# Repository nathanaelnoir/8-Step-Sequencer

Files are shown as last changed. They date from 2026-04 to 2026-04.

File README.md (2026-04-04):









<h1>ℤ₈ Modulo-8 Sequencer</h1>

Modulo-8 Sequencer is an 8-step Eurorack sequencer with an onboard clock, external clock/reset inputs, and separate clock, gate, and CV outputs.

## Contents

- Overview
- Features
- Build & assembly notes
- Testing
- License & contributing

## Overview

This repository contains the KiCad 9 design files for Modulo-8 Sequencer, a straightforward 8-step CV/gate sequencer for Eurorack. Eight pots set the step voltages, the LEDs show the current position, and the module can run from its own clock or from an external pulse. `CLOCK OUT`, `GATE OUT`, `CV OUT`, and `RESET` are all available on the front panel.

## Features

- 8-step sequencer built around `CD4017BE` and `TL074`.
- Internal clock plus external `CLOCK IN`.
- Separate `CLOCK OUT`, `GATE OUT`, `CV OUT`, and `RESET` jacks.
- Eight 100 k step pots for setting the sequence voltage.
- Eight step LEDs for visual feedback.
- Rotary switch wired across `Count0` to `Count7` for loop-length / step-count selection.
- Standard Eurorack power: `+12 V / -12 V / GND` on a 10-pin header.
- Mixed build: SMD passives, diodes, and transistors, with through-hole panel hardware.

## Build & assembly notes

- Check pin-1 orientation on `U1` (`TL074`) and `U3` (`CD4017BE`) before soldering.
- Double-check the Eurorack power header orientation before applying power. Getting that wrong is an easy way to ruin the build.
- Panel hardware is not minimal: five 3.5 mm jacks, eight step pots, eight LEDs, several toggle switches, one rotary switch, and two trimmers (`RV1`, `RV2`).
- The power section includes ferrite beads and local decoupling on the rails. Populate it exactly as shown.
- This is a mixed SMD + THT build, so it makes sense to solder the low-profile SMD parts first and leave the panel hardware for last.

## Testing

1. Power the module from a current-limited Eurorack supply and verify `+12 V`, `-12 V`, and `GND` at the header and test points before patching anything.
2. Let the internal clock run and check that the step LEDs advance in order and that `CLOCK OUT` is pulsing.
3. Feed a known clock into `CLOCK IN` and confirm the sequence advances cleanly from the external source.
4. Trigger `RESET` and make sure the sequencer returns to step 1 or to the selected loop point.
5. Watch `GATE OUT` and `CV OUT` on a scope or with downstream modules and confirm that the outputs follow the programmed steps.

## License & contributing

No `LICENSE` file has been added to this repository yet. Until that changes, assume the design is shared for reference, not under an explicit open-source license.

If a license is added later, this section can be updated properly.

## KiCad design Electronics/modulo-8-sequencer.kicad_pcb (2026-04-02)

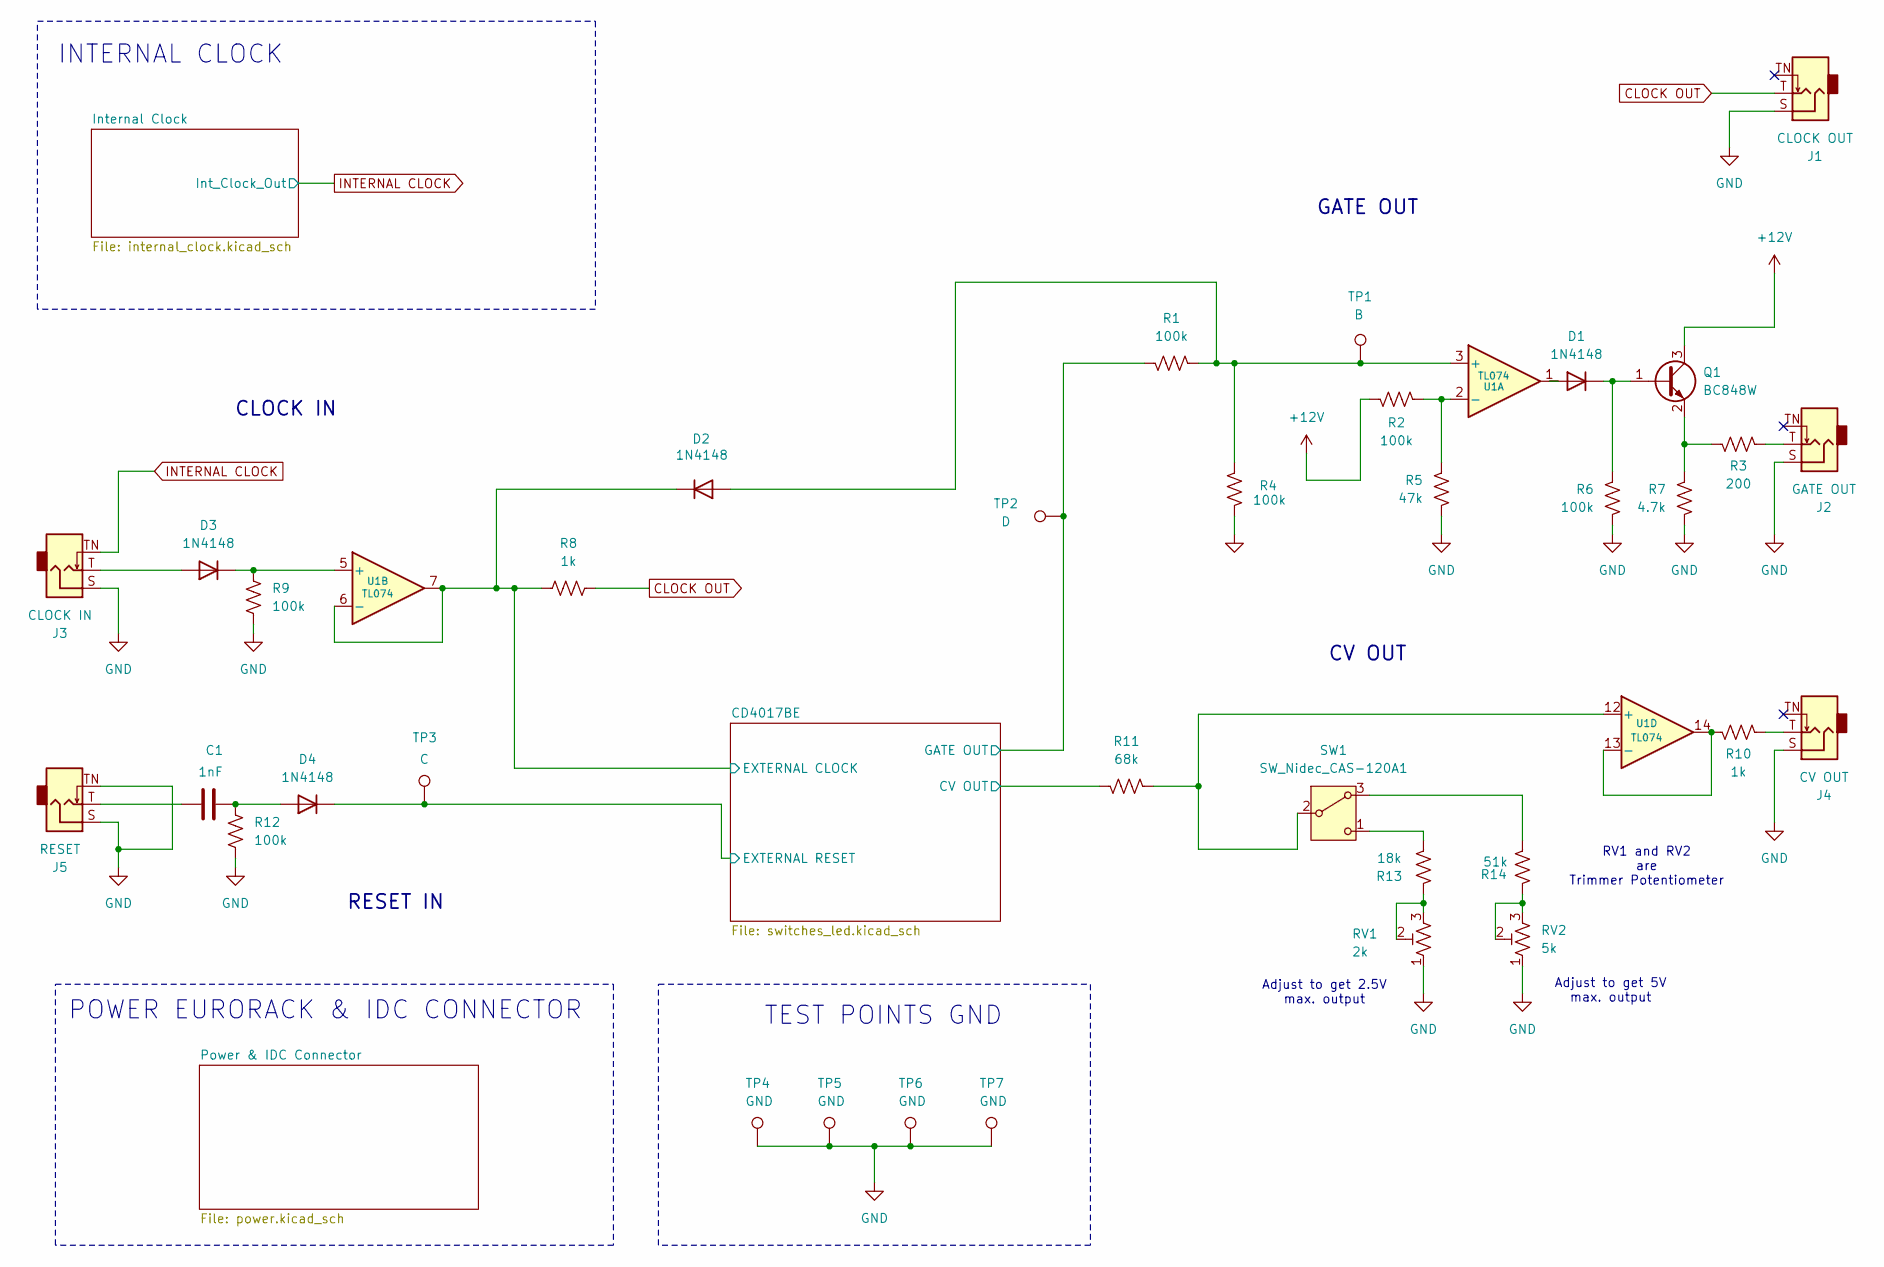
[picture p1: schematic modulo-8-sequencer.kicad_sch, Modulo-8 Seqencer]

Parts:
C1: 1nF; C_0805_2012Metric_Pad1.18x1.45mm_HandSolder
D1, D2, D3, D4: 1N4148; D_SOD-323_HandSoldering
J1: CLOCK OUT; Jack_3.5mm_QingPu_WQP-PJ398SM_Vertical
J2: GATE OUT; Jack_3.5mm_QingPu_WQP-PJ398SM_Vertical
J3: CLOCK IN; Jack_3.5mm_QingPu_WQP-PJ398SM_Vertical
J4: CV OUT; Jack_3.5mm_QingPu_WQP-PJ398SM_Vertical
J5: RESET; Jack_3.5mm_QingPu_WQP-PJ398SM_Vertical
Q1: BC848W; SOT-323_SC-70
R1, R2, R4, R6, R9, R12: 100k; R_0805_2012Metric_Pad1.20x1.40mm_HandSolder
R3: 200; R_0805_2012Metric_Pad1.20x1.40mm_HandSolder
R5: 47k; R_0805_2012Metric_Pad1.20x1.40mm_HandSolder
R7: 4.7k; R_0805_2012Metric_Pad1.20x1.40mm_HandSolder
R8, R10: 1k; R_0805_2012Metric_Pad1.20x1.40mm_HandSolder
R11: 68k; R_0805_2012Metric_Pad1.20x1.40mm_HandSolder
R13: 18k; R_0805_2012Metric_Pad1.20x1.40mm_HandSolder
R14: 51k; R_0805_2012Metric_Pad1.20x1.40mm_HandSolder
RV1: 2k; Trimmer_Bourns_3296W_50k_THT
RV2: 5k; Trimmer_Bourns_3296W_50k_THT
SW1: SW_Nidec_CAS-120A1; Switch_Toggle_Dailywell_MS1T1B1M2QES_SPDT
TP1: B; TestPoint_Pad_D1.5mm
TP2: D; TestPoint_Pad_D1.5mm
TP3: C; TestPoint_Pad_D1.5mm
TP4, TP5, TP6, TP7: GND; TestPoint_Pad_D1.5mm
U1: TL074; SOIC-14_3.9x8.7mm_P1.27mm

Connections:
+12V: Q1.3 (C), R2.1; also elsewhere on the board
/CD4017BE/CV OUT: R11.1; also elsewhere on the board
/CD4017BE/EXTERNAL CLOCK: D2.1 (K), R8.2, U1.6 (-), U1.7; also elsewhere on the board
/CD4017BE/EXTERNAL RESET: D4.1 (K), TP3.1; also elsewhere on the board
/CD4017BE/GATE OUT: R1.1, TP2.1; also elsewhere on the board
CLOCK OUT: J1.T, R8.1
GND: J1.S, J2.S, J3.S, J4.S, J5.S, J5.TN, R4.1, R5.1, R6.1, R7.1, R9.1, R12.1, RV1.1, RV2.1, TP4.1, TP5.1, TP6.1, TP7.1; also elsewhere on the board
INTERNAL CLOCK: J3.TN; also elsewhere on the board
unnamed: C1.2, J5.T
unnamed: D1.2 (A), U1.1
unnamed: D1.1 (K), Q1.1 (B), R6.2
unnamed: D2.2 (A), R1.2, R4.2, TP1.1, U1.3 (+)
unnamed: D3.2 (A), J3.T
unnamed: D3.1 (K), R9.2, U1.5 (+)
unnamed: C1.1, D4.2 (A), R12.2
unnamed: J2.T, R3.1
unnamed: J4.T, R10.1
unnamed: Q1.2 (E), R3.2, R7.2
unnamed: R13.1, RV1.2, RV1.3
unnamed: R14.1, RV2.2, RV2.3
unnamed: R14.2, SW1.3 (A)
unnamed: R11.2, SW1.2 (B), U1.12 (+)
unnamed: R13.2, SW1.1 (C)
unnamed: R2.2, R5.2, U1.2 (-)
unnamed: R10.2, U1.13 (-), U1.14

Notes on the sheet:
POWER EURORACK & IDC CONNECTOR
Adjust to get 2.5V max. output
RV1 and RV2 are Trimmer Potentiometer
TEST POINTS GND
INTERNAL CLOCK
Adjust to get 5V max. output
CV OUT
GATE OUT
RESET IN
CLOCK IN

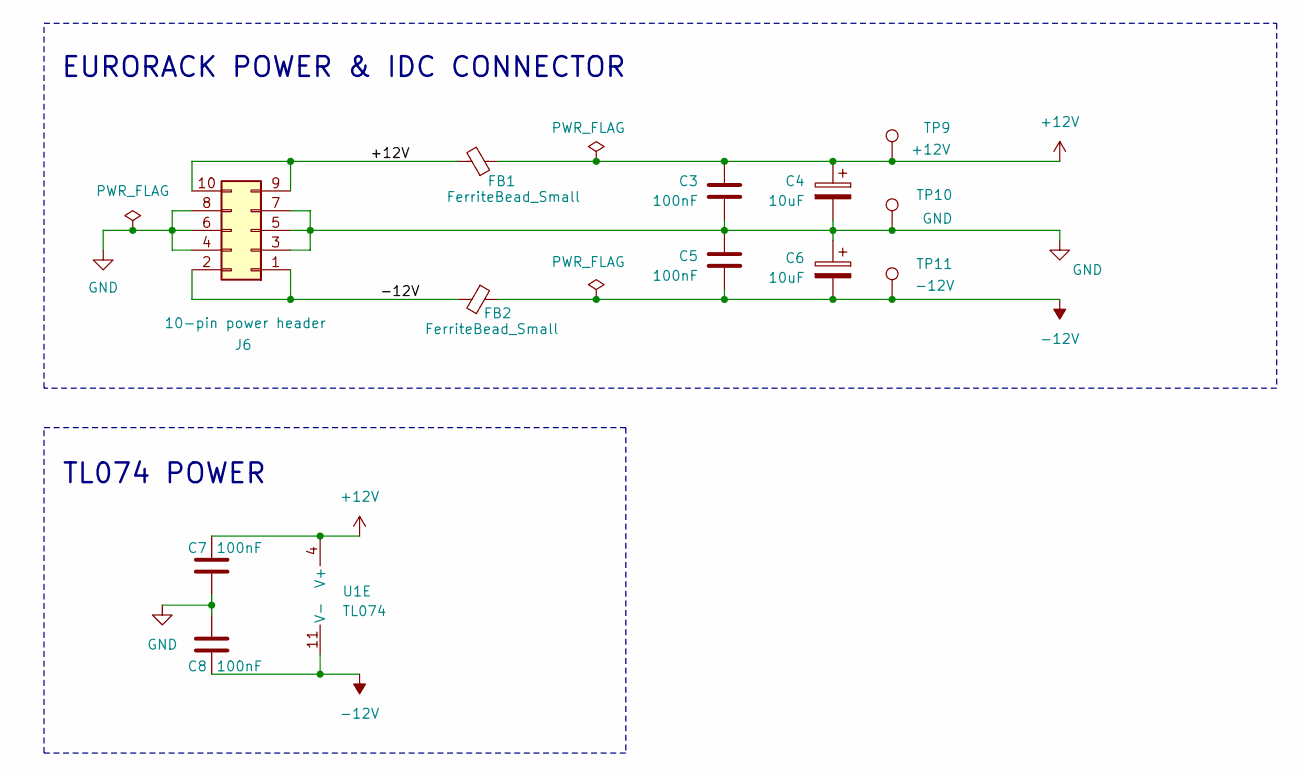
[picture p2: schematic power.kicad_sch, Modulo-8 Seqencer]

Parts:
C3, C5, C7, C8: 100nF; C_0805_2012Metric_Pad1.18x1.45mm_HandSolder
C4, C6: 10uF; CP_Elec_5x5.4
FB1, FB2: FerriteBead_Small; L_0805_2012Metric_Pad1.05x1.20mm_HandSolder
J6: 10-pin power header; IDC-Header_2x05_P2.54mm_Vertical
TP9: +12V; TestPoint_Pad_D1.5mm
TP10: GND; TestPoint_Pad_D1.5mm
TP11: -12V; TestPoint_Pad_D1.5mm
U1: TL074; SOIC-14_3.9x8.7mm_P1.27mm

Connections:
+12V: C3.1, C4.1, C7.1, FB1.1, FB1.2, J6.9, J6.10, TP9.1, U1.4 (V+); also elsewhere on the board
-12V: C5.2, C6.2, C8.2, FB2.1, FB2.2, J6.1, J6.2, TP11.1, U1.11 (V-)
GND: C3.2, C4.2, C5.1, C6.1, C7.2, C8.1, J6.3, J6.4, J6.5, J6.6, J6.7, J6.8, TP10.1; also elsewhere on the board

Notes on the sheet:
TL074 POWER
EURORACK POWER & IDC CONNECTOR

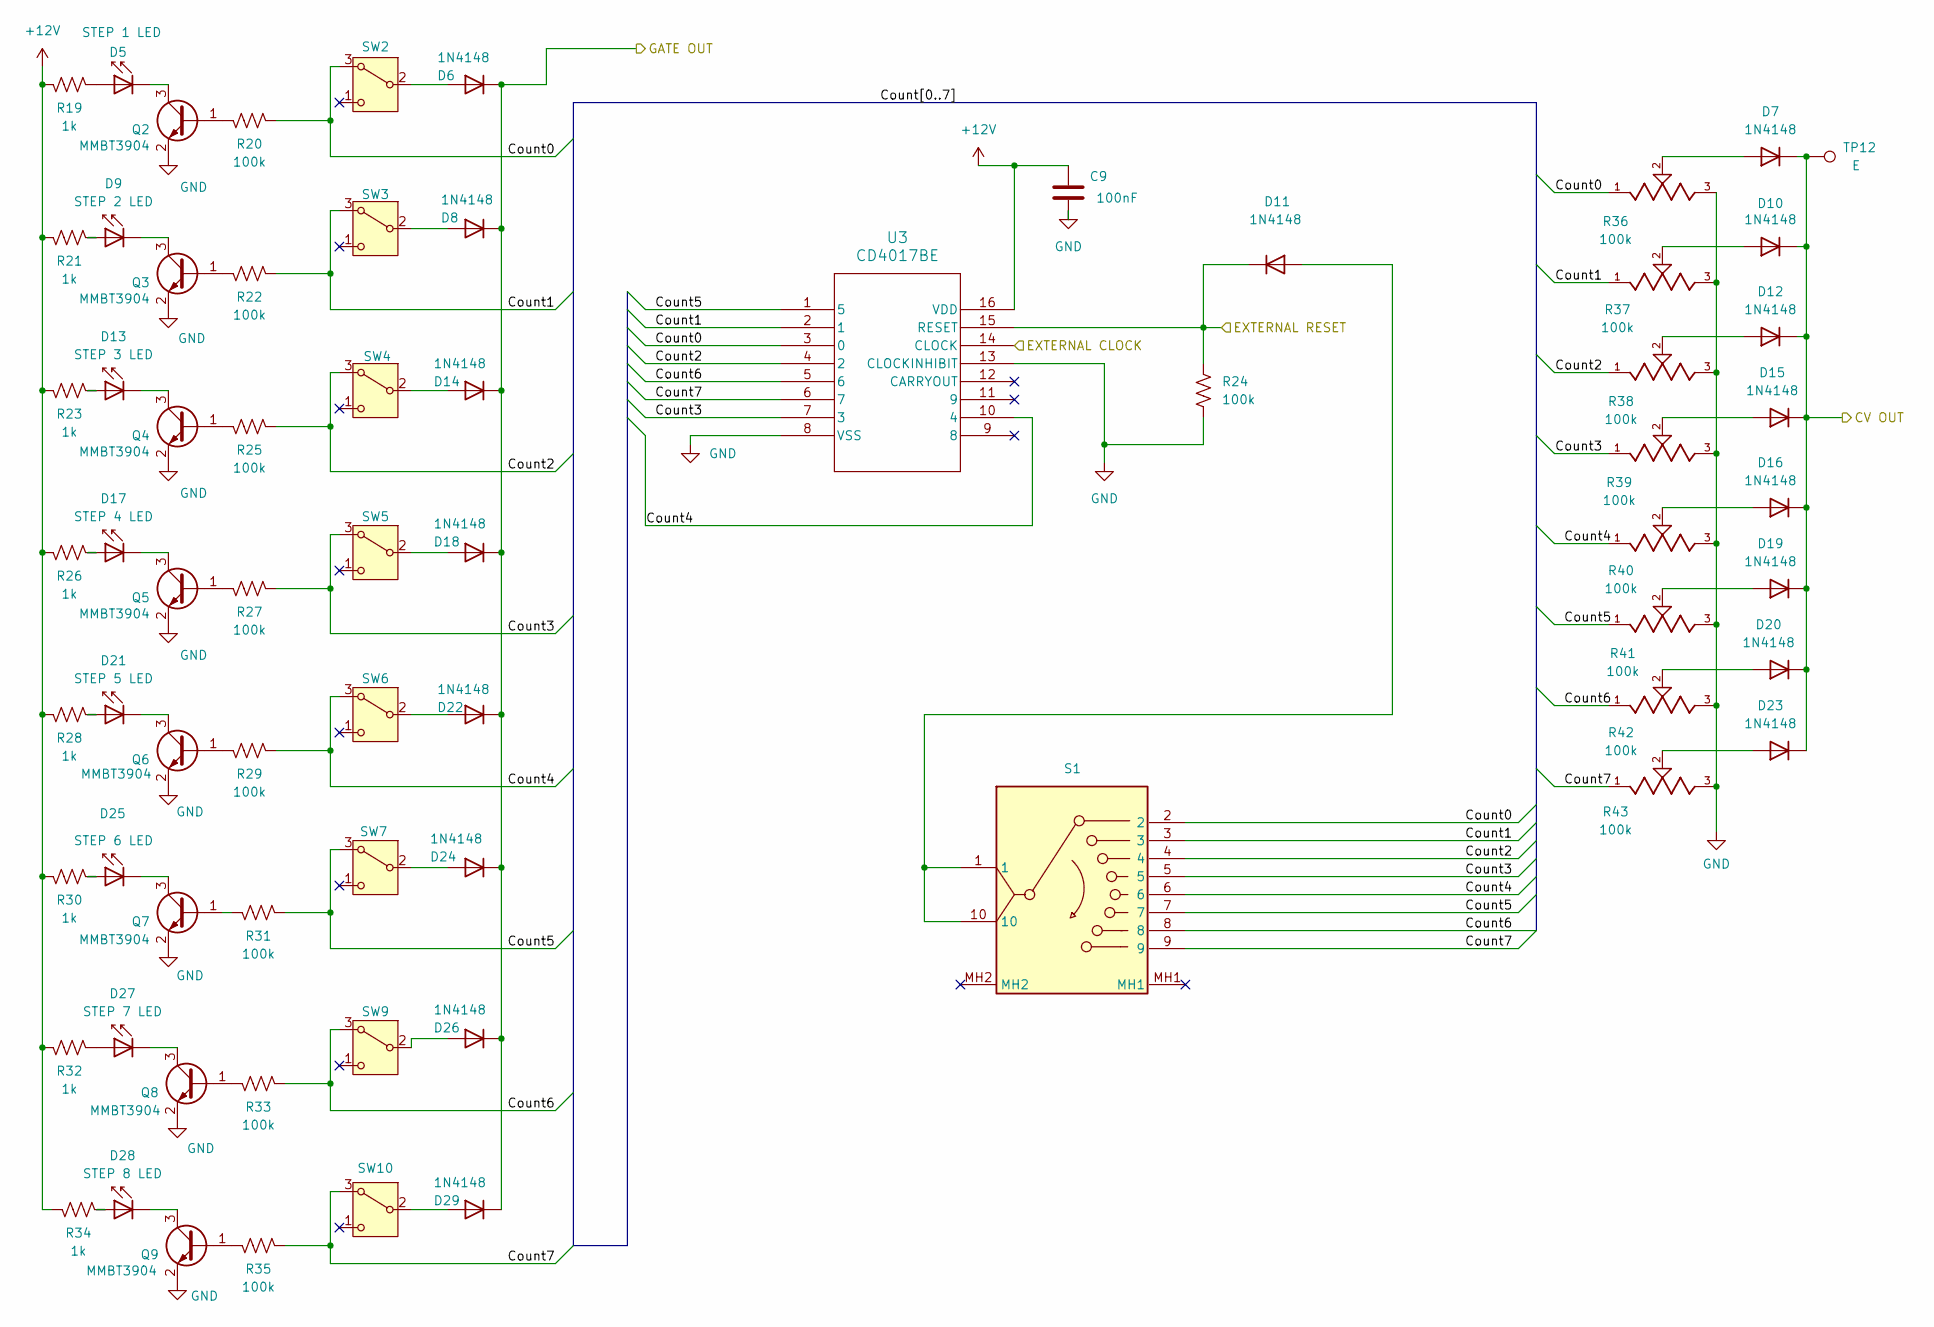
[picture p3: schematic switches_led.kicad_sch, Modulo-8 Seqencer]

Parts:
C9: 100nF; C_0805_2012Metric_Pad1.18x1.45mm_HandSolder
D5: STEP 1 LED; LED_D3.0mm_Clear
D6, D7, D8, D10, D11, D12, D14, D15, D16, D18, D19, D20, D22, D23, D24, D26, D29: 1N4148; D_SOD-323_HandSoldering
D9: STEP 2 LED; LED_D3.0mm_Clear
D13: STEP 3 LED; LED_D3.0mm_Clear
D17: STEP 4 LED; LED_D3.0mm_Clear
D21: STEP 5 LED; LED_D3.0mm_Clear
D25: STEP 6 LED; LED_D3.0mm_Clear
D27: STEP 7 LED; LED_D3.0mm_Clear
D28: STEP 8 LED; LED_D3.0mm_Clear
Q2, Q3, Q4, Q5, Q6, Q7, Q8, Q9: MMBT3904; SOT-23
R19, R21, R23, R26, R28, R30, R32, R34: 1k; R_0805_2012Metric_Pad1.20x1.40mm_HandSolder
R20, R22, R24, R25, R27, R29, R31, R33, R35: 100k; R_0805_2012Metric_Pad1.20x1.40mm_HandSolder
R36, R37, R38, R39, R40, R41, R42, R43: 100k; Potentiometer_Alpha_RD901F_Vertical_Alt
S1: Switch_Rotary_Alpha_SR1712F_1P8T; Mouser Part Number 105-SR1712F-18NS
SW2, SW3, SW4, SW5, SW6, SW7, SW9, SW10: Switch_Toggle_Dailywell_MS1T1B1M2QES_SPDT
TP12: E; TestPoint_Pad_D1.5mm
U3: CD4017BE; IC_DIP-16_CD4017BE_THT

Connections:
+12V: C9.1, R19.1, R21.1, R23.1, R26.1, R28.1, R30.1, R32.1, R34.1, U3.16 (VDD); also elsewhere on the board
/CD4017BE/CV OUT: D7.1 (K), D10.1 (K), D12.1 (K), D15.1 (K), D16.1 (K), D19.1 (K), D20.1 (K), D23.1 (K), TP12.1; also elsewhere on the board
/CD4017BE/Count0: R20.2, R36.1, S1.2, SW2.3 (A), U3.3 (0)
/CD4017BE/Count1: R22.2, R37.1, S1.3, SW3.3 (A), U3.2 (1)
/CD4017BE/Count2: R25.2, R38.1, S1.4, SW4.3 (A), U3.4 (2)
/CD4017BE/Count3: R27.2, R39.1, S1.5, SW5.3 (A), U3.7 (3)
/CD4017BE/Count4: R29.2, R40.1, S1.6, SW6.3 (A), U3.10 (4)
/CD4017BE/Count5: R31.2, R41.1, S1.7, SW7.3 (A), U3.1 (5)
/CD4017BE/Count6: R33.2, R42.1, S1.8, SW9.3 (A), U3.5 (6)
/CD4017BE/Count7: R35.2, R43.1, S1.9, SW10.3 (A), U3.6 (7)
/CD4017BE/EXTERNAL CLOCK: U3.14 (CLOCK); also elsewhere on the board
/CD4017BE/EXTERNAL RESET: D11.1 (K), R24.2, U3.15 (RESET); also elsewhere on the board
/CD4017BE/GATE OUT: D6.1 (K), D8.1 (K), D14.1 (K), D18.1 (K), D22.1 (K), D24.1 (K), D26.1 (K), D29.1 (K); also elsewhere on the board
GND: C9.2, Q2.2 (E), Q3.2 (E), Q4.2 (E), Q5.2 (E), Q6.2 (E), Q7.2 (E), Q8.2 (E), Q9.2 (E), R24.1, R36.3, R37.3, R38.3, R39.3, R40.3, R41.3, R42.3, R43.3, U3.8 (VSS), U3.13 (CLOCKINHIBIT); also elsewhere on the board
unnamed: D5.2 (A), R19.2
unnamed: D5.1 (K), Q2.3 (C)
unnamed: D6.2 (A), SW2.2 (B)
unnamed: D7.2 (A), R36.2
unnamed: D8.2 (A), SW3.2 (B)
unnamed: D9.2 (A), R21.2
unnamed: D9.1 (K), Q3.3 (C)
unnamed: D10.2 (A), R37.2
unnamed: D11.2 (A), S1.1, S1.10
unnamed: D12.2 (A), R38.2
unnamed: D13.2 (A), R23.2
unnamed: D13.1 (K), Q4.3 (C)
unnamed: D14.2 (A), SW4.2 (B)
unnamed: D15.2 (A), R39.2
unnamed: D16.2 (A), R40.2
unnamed: D17.2 (A), R26.2
unnamed: D17.1 (K), Q5.3 (C)
unnamed: D18.2 (A), SW5.2 (B)
unnamed: D19.2 (A), R41.2
unnamed: D20.2 (A), R42.2
unnamed: D21.2 (A), R28.2
unnamed: D21.1 (K), Q6.3 (C)
unnamed: D22.2 (A), SW6.2 (B)
unnamed: D23.2 (A), R43.2
unnamed: D24.2 (A), SW7.2 (B)
unnamed: D25.2 (A), R30.2
unnamed: D25.1 (K), Q7.3 (C)
unnamed: D26.2 (A), SW9.2 (B)
unnamed: D27.2 (A), R32.2
unnamed: D27.1 (K), Q8.3 (C)
unnamed: D28.2 (A), R34.2
unnamed: D28.1 (K), Q9.3 (C)
unnamed: D29.2 (A), SW10.2 (B)
unnamed: Q2.1 (B), R20.1
unnamed: Q3.1 (B), R22.1
unnamed: Q4.1 (B), R25.1
unnamed: Q5.1 (B), R27.1
unnamed: Q6.1 (B), R29.1
unnamed: Q7.1 (B), R31.1
unnamed: Q8.1 (B), R33.1
unnamed: Q9.1 (B), R35.1

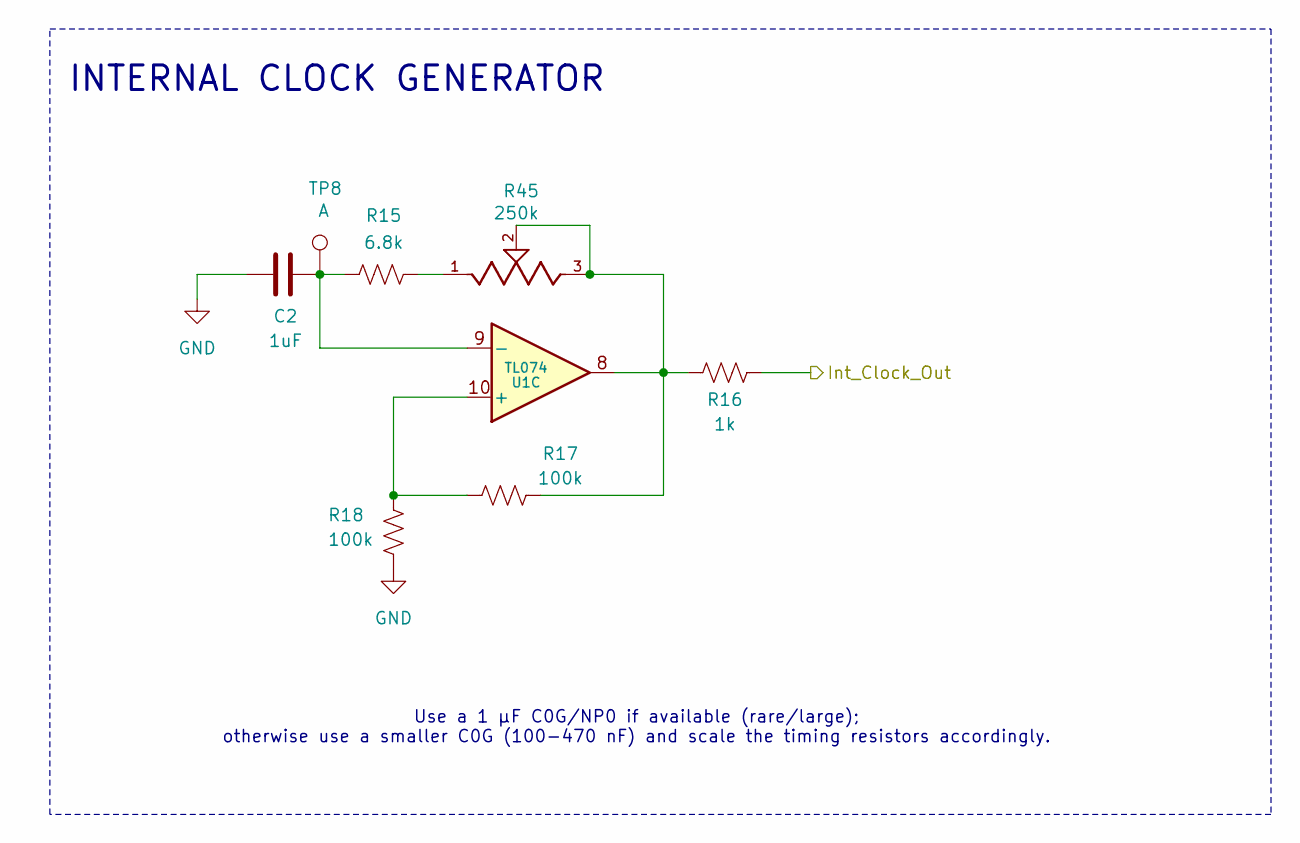
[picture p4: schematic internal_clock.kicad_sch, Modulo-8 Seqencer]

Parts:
C2: 1uF; Capacitor_Film_KEMET_R82DC4100AA60J_THT
R15: 6.8k; R_0805_2012Metric_Pad1.20x1.40mm_HandSolder
R16: 1k; R_0805_2012Metric_Pad1.20x1.40mm_HandSolder
R17, R18: 100k; R_0805_2012Metric_Pad1.20x1.40mm_HandSolder
R45: 250k; Potentiometer_Alpha_RD901F_Vertical_Alt
TP8: A; TestPoint_Pad_D1.5mm
U1: TL074; SOIC-14_3.9x8.7mm_P1.27mm

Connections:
GND: C2.1, R18.1; also elsewhere on the board
INTERNAL CLOCK: R16.1; also elsewhere on the board
unnamed: R15.1, R45.1
unnamed: R16.2, R17.1, R45.2, R45.3, U1.8
unnamed: R17.2, R18.2, U1.10 (+)
unnamed: C2.2, R15.2, TP8.1, U1.9 (-)

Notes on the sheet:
INTERNAL CLOCK GENERATOR
Use a 1 µF C0G/NP0 if available (rare/large); otherwise use a smaller C0G (100-470 nF) and scale the timing resistors accordingly.

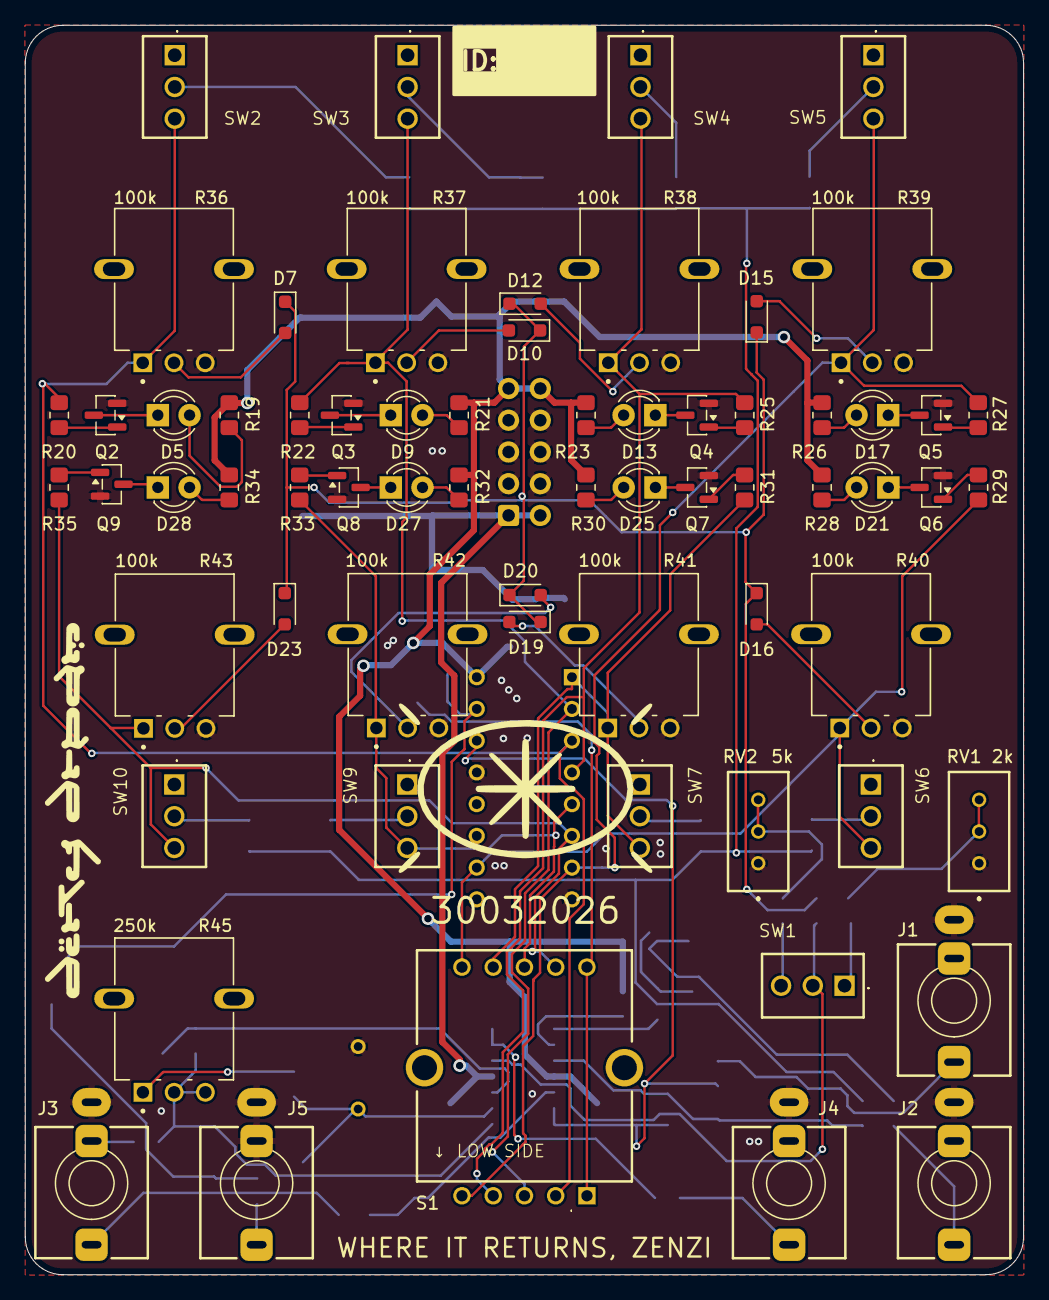
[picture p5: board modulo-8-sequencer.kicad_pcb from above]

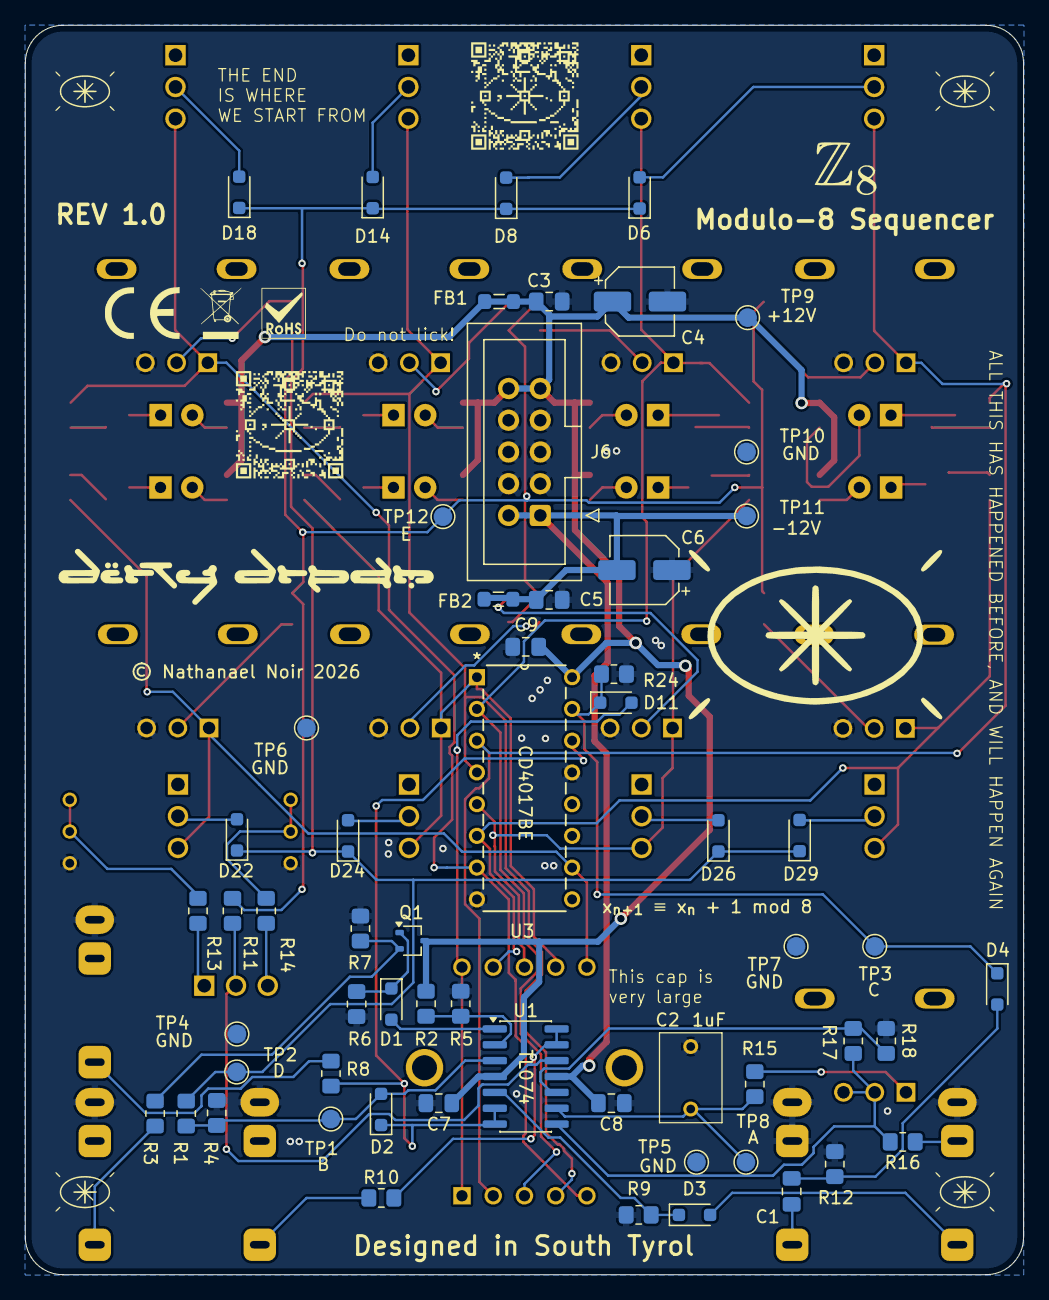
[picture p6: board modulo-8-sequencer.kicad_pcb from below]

Board: 2 copper layers, 79.9 x 100.0 mm, 125 parts (59 on the bottom side), 79 nets.

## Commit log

2026-03-09 schematic: update cicada schematic
    [internal_clock.kicad_sch, power.kicad_sch, sequencer.kicad_sch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]
2026-03-10 refactor(kicad): move switch/LED driver logic into switches_led sheet
    [power.kicad_sch, sequencer.kicad_sch, switches_led.kicad_sch]
2026-03-10 refactor(kicad): finishing root
    [sequencer.kicad_sch, switches_led.kicad_sch]
2026-03-10 refactor(kicad): first ERC run
    [sequencer.kicad_sch, switches_led.kicad_sch]
2026-03-13 Refine KiCad schematics for power, test points, and control values
    - replace schematic +12V/-12V global labels with proper power symbols
    - add GND test points and reorganize the power/IDC and main sequencer
    sheets
    - retune sequencer values including R33/R34 to 51k, R35 to 68k, C8 to
    1nF, and trim pots to 2k/5k
    - update switch/LED sheet labels and pot values, renaming LEDs by step
    and changing B250k controls to B100k
    - relax the KiCad four-way junction ERC setting in the project file
    [power.kicad_sch, sequencer.kicad_sch, switches_led.kicad_sch]
2026-03-13 Updating sheet names
    [internal_clock.kicad_sch, power.kicad_sch, sequencer.kicad_sch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]
2026-03-14 adding missing footprints to the power supply
    [power.kicad_sch]
2026-03-15 adding missing SMD footprints
    [internal_clock.kicad_sch, power.kicad_sch, sequencer.kicad_sch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]
2026-03-15 adding Test Point D
    [internal_clock.kicad_sch, power.kicad_sch, sequencer.kicad_sch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]
2026-03-16 adding footprints
    [sequencer.kicad_sch, switches_led.kicad_sch]
2026-03-18 adding footprint for rotary switch P1S8
    [sequencer.kicad_sch, switches_led.kicad_sch]
2026-03-19 adding new rotary switch
    [switches_led.kicad_sch]
2026-03-19 initiating pcb layout
    [internal_clock.kicad_sch, power.kicad_sch, sequencer.kicad_pcb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]
2026-03-21 placing layout frontview
    [internal_clock.kicad_sch, power.kicad_sch, sequencer.kicad_pcb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]
2026-03-21 fixing some errors in schematics; first component placement
    [power.kicad_sch, sequencer.kicad_pcb, switches_led.kicad_sch]
2026-03-22 connecting all components and adding copper layers, vias tracks…
    [sequencer.kicad_pcb]
2026-03-23 rerouting and editing silkscreen
    [sequencer.kicad_pcb]
2026-03-24 re-placing components; optimizing text on silkscreen
    [internal_clock.kicad_sch, sequencer.kicad_pcb, sequencer.kicad_sch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]
2026-03-25 changing position on silkscreen
    [sequencer.kicad_pcb, sequencer.kicad_sch, switches_led.kicad_sch]
2026-03-25 fixing drc errors; mirroring potentiometers in sch due to error; mirroring switches on pcb
    to do: change symbol description potentiometer (cw, ccw)
    [internal_clock.kicad_sch, sequencer.kicad_pcb, switches_led.kicad_sch]
2026-03-27 placing logos
    [sequencer.kicad_pcb]
2026-03-27 finalizing silkscreen
    [sequencer.kicad_pcb]
2026-03-27 adding a README.md
    [sequencer.kicad_pcb]
2026-03-29 adding qr code
    [sequencer.kicad_pcb]
2026-04-02 new logo, via correction, gerber
    [internal_clock.kicad_sch, power.kicad_sch, sequencer.kicad_pcb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]
2026-04-02 changing folder name
    [internal_clock.kicad_sch, power.kicad_sch, sequencer.kicad_pcb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]
2026-04-02 changing file names
    [modulo-8-sequencer.kicad_pcb, modulo-8-sequencer.kicad_sch]

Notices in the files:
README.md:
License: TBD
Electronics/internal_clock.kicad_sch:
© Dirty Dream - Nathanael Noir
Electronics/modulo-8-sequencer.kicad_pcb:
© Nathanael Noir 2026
